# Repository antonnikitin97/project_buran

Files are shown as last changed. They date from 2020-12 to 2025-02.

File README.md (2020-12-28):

# project_buran
Files pertaining to my home-made Stream Deck project. 

## Motivation
I don't want to pay £150 for a stream deck

## Why Buran?
I decided some time ago to name all my personal projects after Russian space missions, буран (meaning, blizzard in Russian) was the Soviet Union's/Russia's attempt at a fully automated shuttle, it flew once successfully but was canned due to funding issues and the only existing model being destroyed.

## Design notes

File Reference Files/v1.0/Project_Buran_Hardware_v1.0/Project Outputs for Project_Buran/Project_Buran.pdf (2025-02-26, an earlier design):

Comment | Description | Designator | Footprint | LibRef | Quantity
GRM188R60J106ME47D | Chip Multilayer Ceramic Capacitors for General Purpose, 0603, 10uF, X5R, 15%, 20%, 6.3V | C1, C2, C11, C13, C14 | FP-GRM188-0_1-e0_2_0_55-IPC_A | CMP-2006-02792-2 | 5
ATSAMD11D14A-SSUT | Integrated Circuit | IC1 | SOIC127P1032X265-20N | ATSAMD11D14A-SSUT | 1
MAX803SQ308T1G | Integrated Circuit | IC2 | SOT65P220X100-3N | MAX803SQ308T1G | 1
LP5012RUKR | Integrated Circuit | IC5 | QFN40P300X300X80-21N-D | LP5012RUKR | 1
292303-7 | CONN RCPT USB2.0 TYPEA 4P SMD RA | J2 | FP-292303-7-MFG | CMP-03360-000008-1 | 1
61301021121 | THT Vertical Pin Header WR-PHD, Pitch 2.54 mm, Dual Row, 10 pins | P1 | 61301021121 | CMP-1502-01084-1 | 1
TLV75733PDBVR | Power Supply | PS1 | SOT95P280X145-5N | TLV75733PDBVR | 1
CRCW0603110RFKEA | | R1, R2, R3, R8 | RESC1609X50X30NL10 T20 | CMP-2000-03854-1 | 4
465M111172501 | WS-PBTL Illuminated THT Push Button Switch, Red & Green & Blue | S9, S11, S13, S15 | 465M111172501 | 465M111172501 | 4
FSM4JSMA | Swicth, SPST, 24 V, -35 to 85 degC, 4-Pin SMD, RoHS, Tape and Reel | SW2 | TECO-FSM4JSMA_V | CMP-2000-05602-2 | 1
AB15T-32.768KHZ | Crystal or Oscillator | Y1 | AB15T32768KHZ | AB15T-32.768KHZ | 1

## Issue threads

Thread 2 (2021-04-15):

Add thermal relief to pads that connect to GND plane

antonnikitin97, 2021-04-15:
This will make it easier to reflow solder on these pads

antonnikitin97, 2021-04-17:
resolved in 03a86d5f0a763ea9e13fac3a59dc2d1cc172d767

Closed 2021-04-17.

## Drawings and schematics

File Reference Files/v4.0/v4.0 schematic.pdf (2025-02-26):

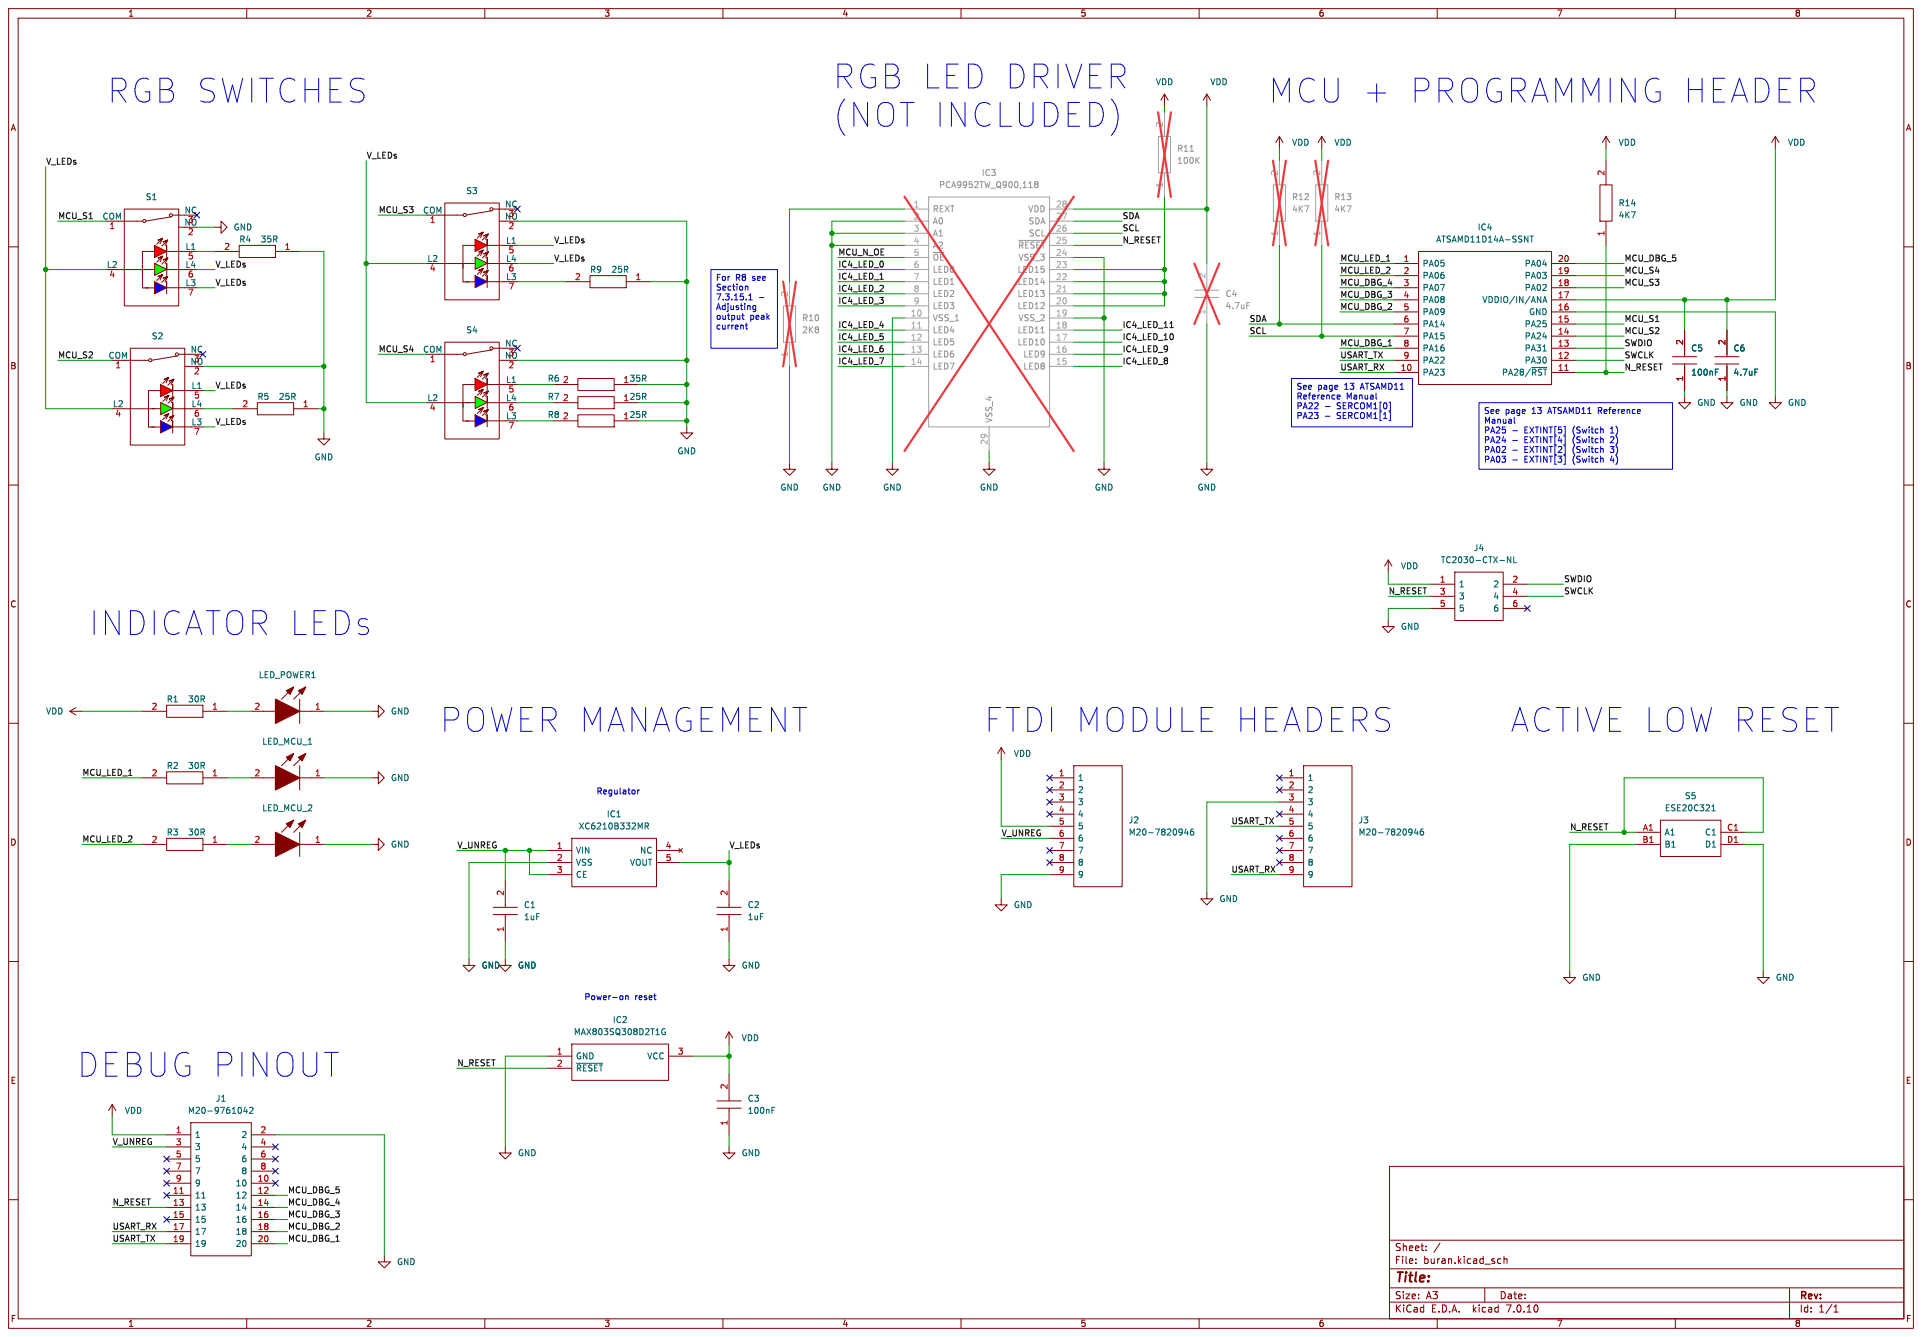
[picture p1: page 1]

See page 13 ATSAMD11 Reference Manual PA25 - EXTINT[5] (Switch 1) PA24 - EXTINT[4] (Switch 2) PA02 - EXTINT[2] (Switch 3) PA03 - EXTINT[3] (Switch 4) For R8 see Section

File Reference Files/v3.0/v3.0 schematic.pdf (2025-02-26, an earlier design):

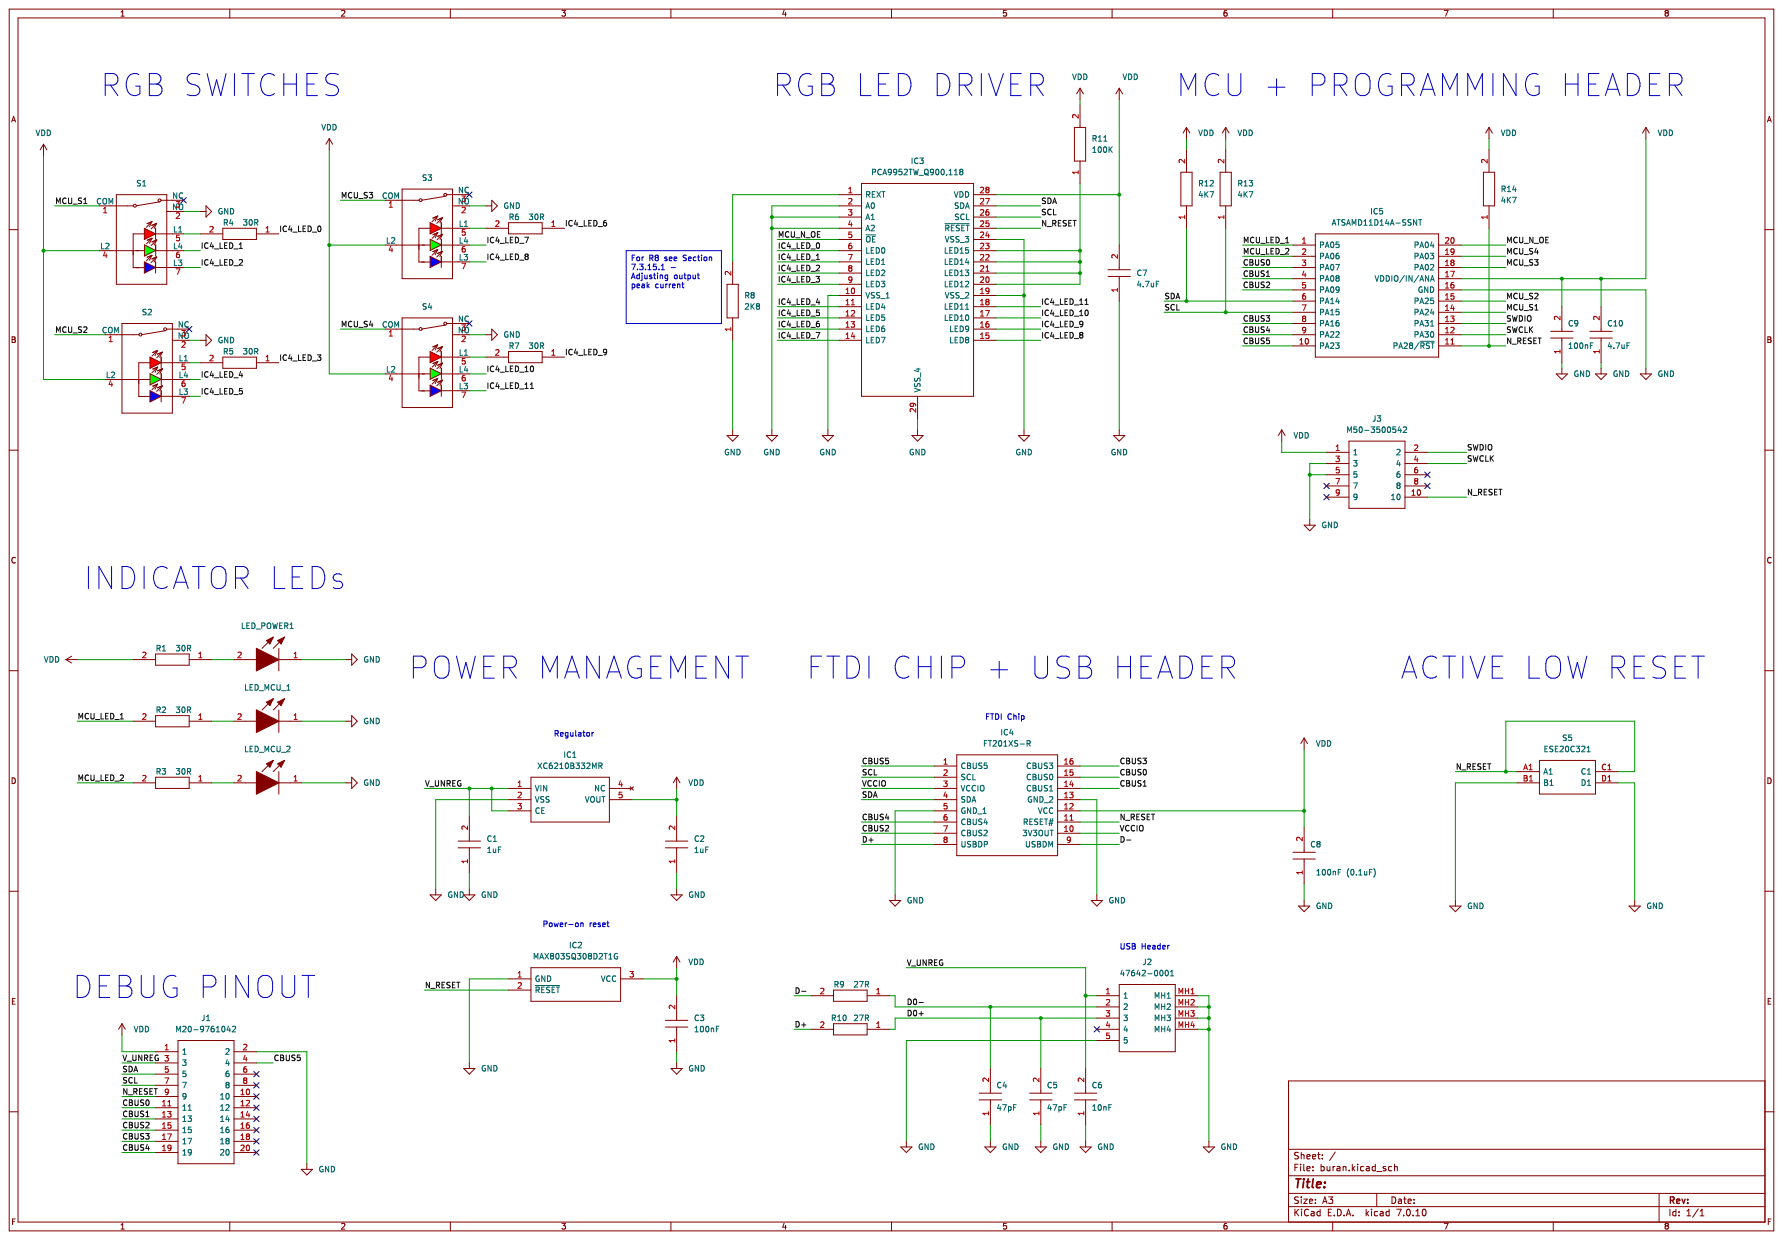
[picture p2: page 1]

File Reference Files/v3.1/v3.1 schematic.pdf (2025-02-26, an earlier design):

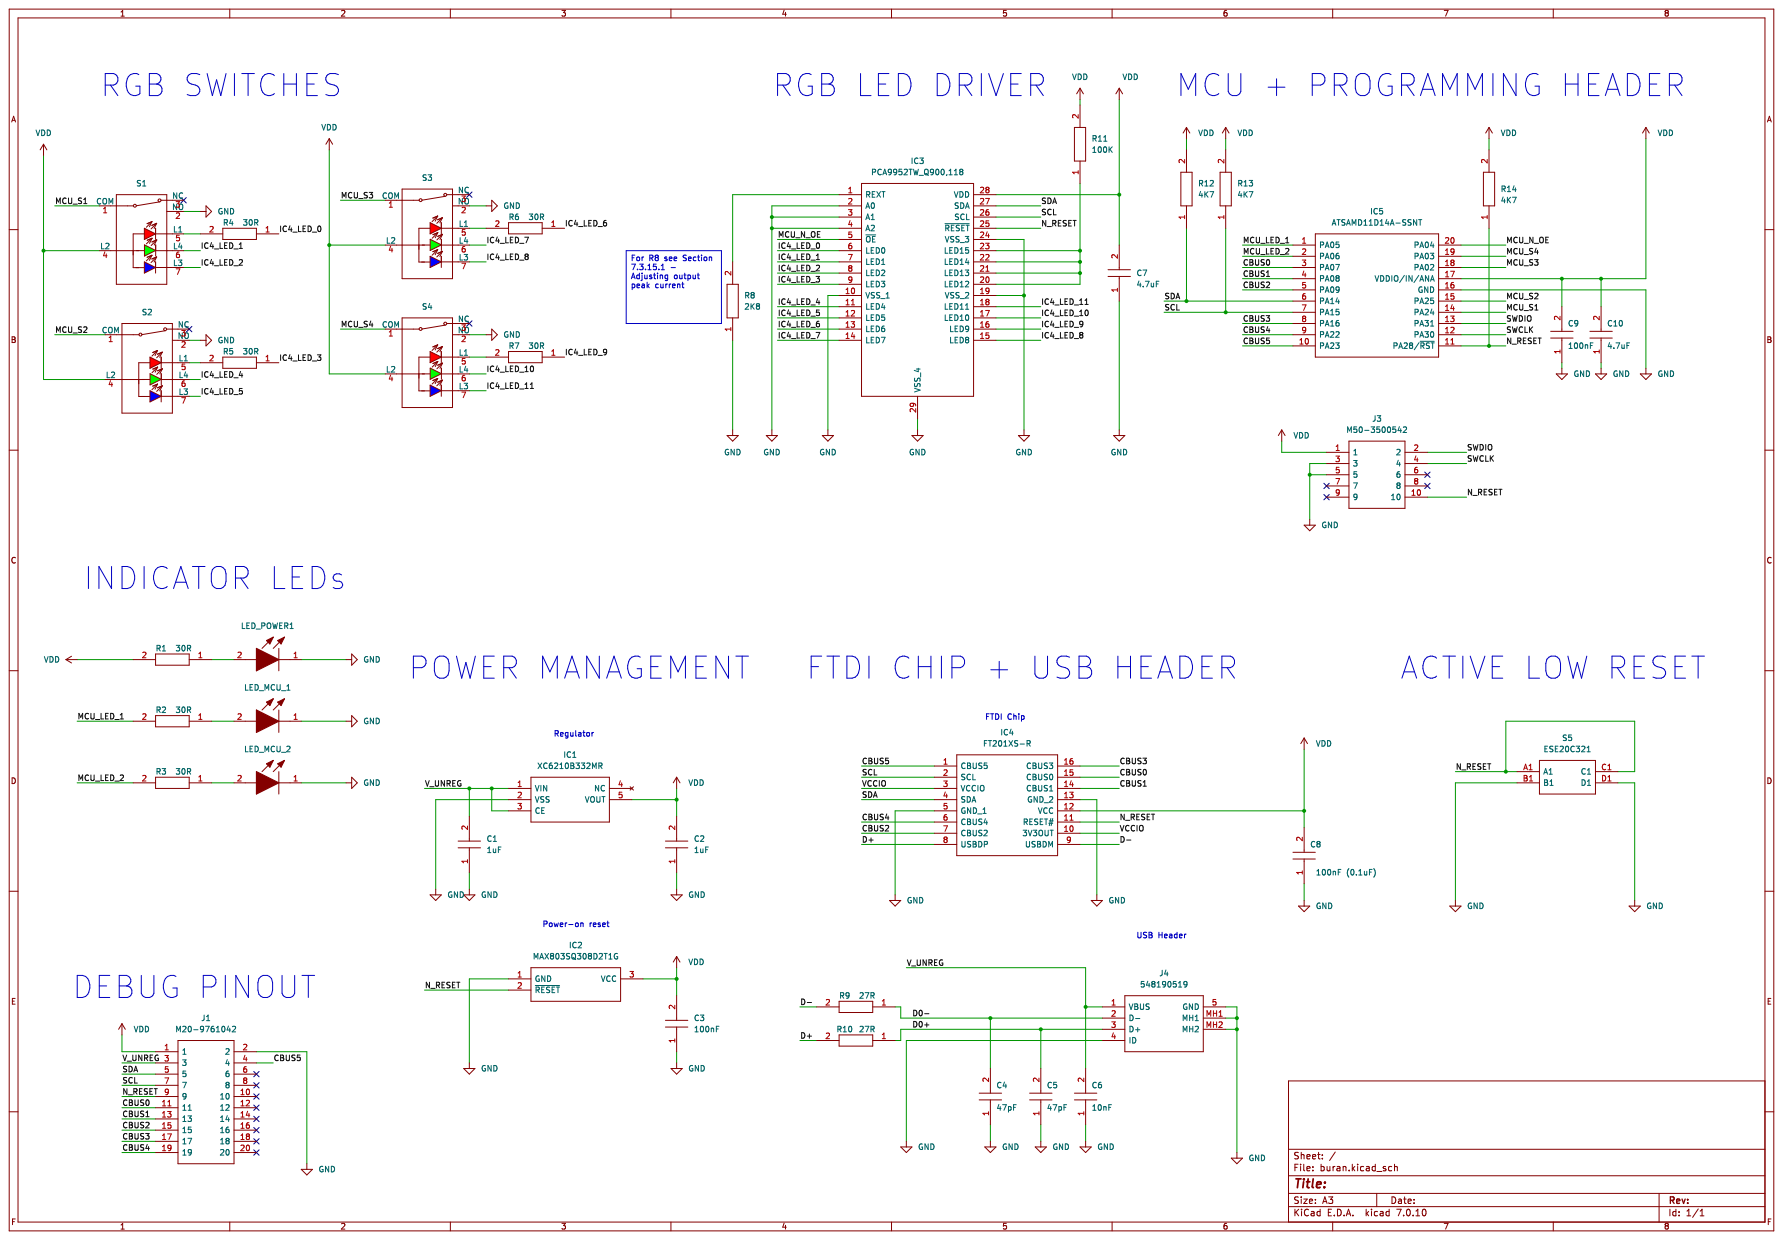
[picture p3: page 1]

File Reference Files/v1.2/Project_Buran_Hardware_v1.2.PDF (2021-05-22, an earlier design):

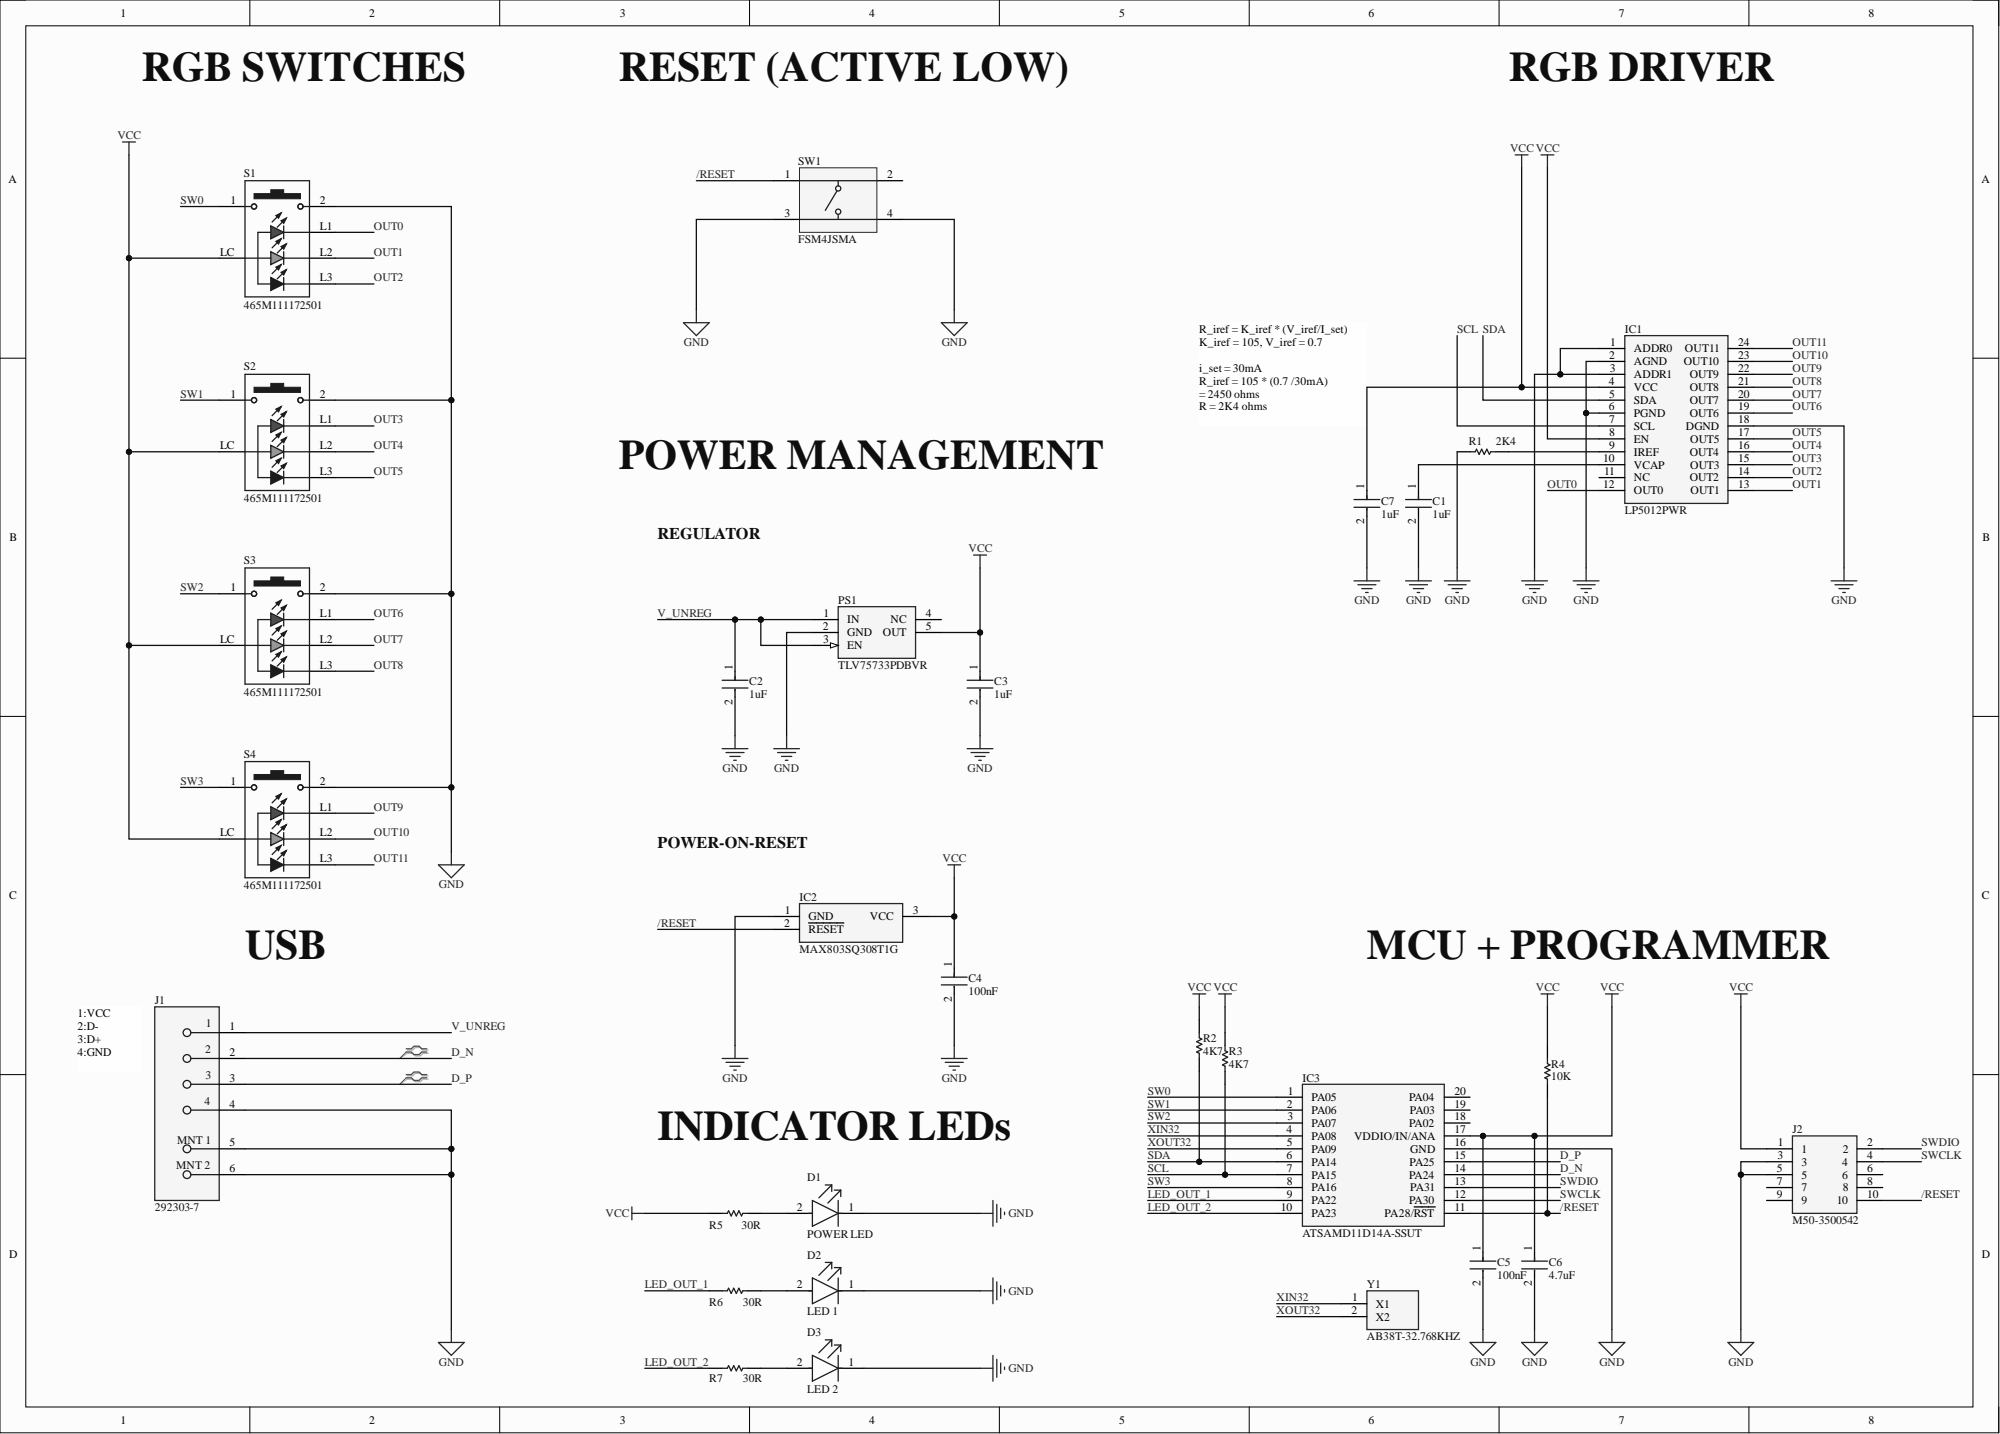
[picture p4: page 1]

AGND 2
ADDR1 3
VCC 4
SDA 5

SCL 7

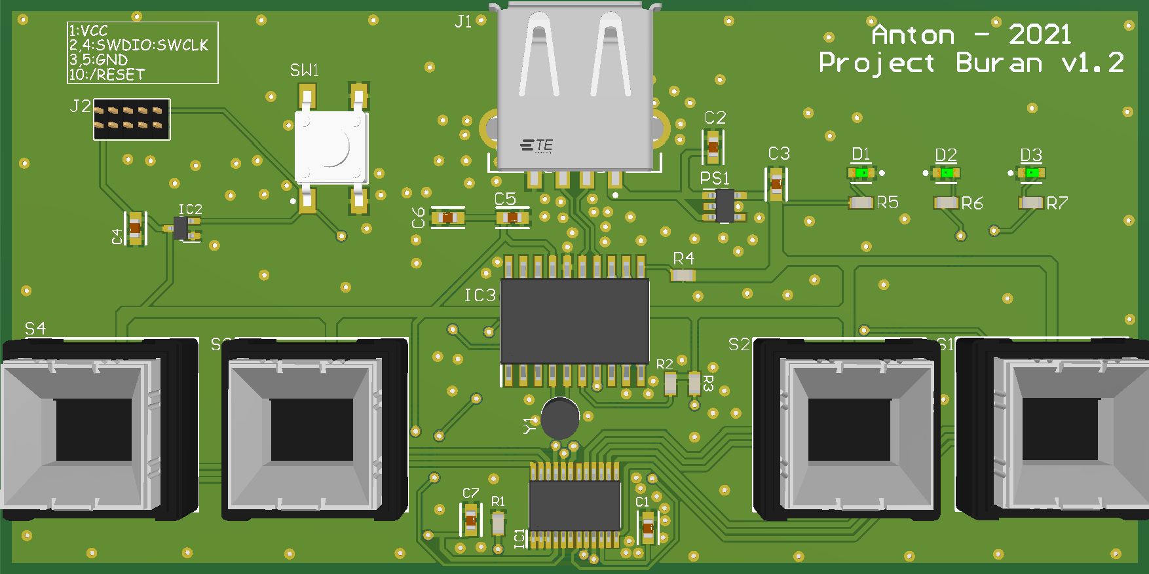
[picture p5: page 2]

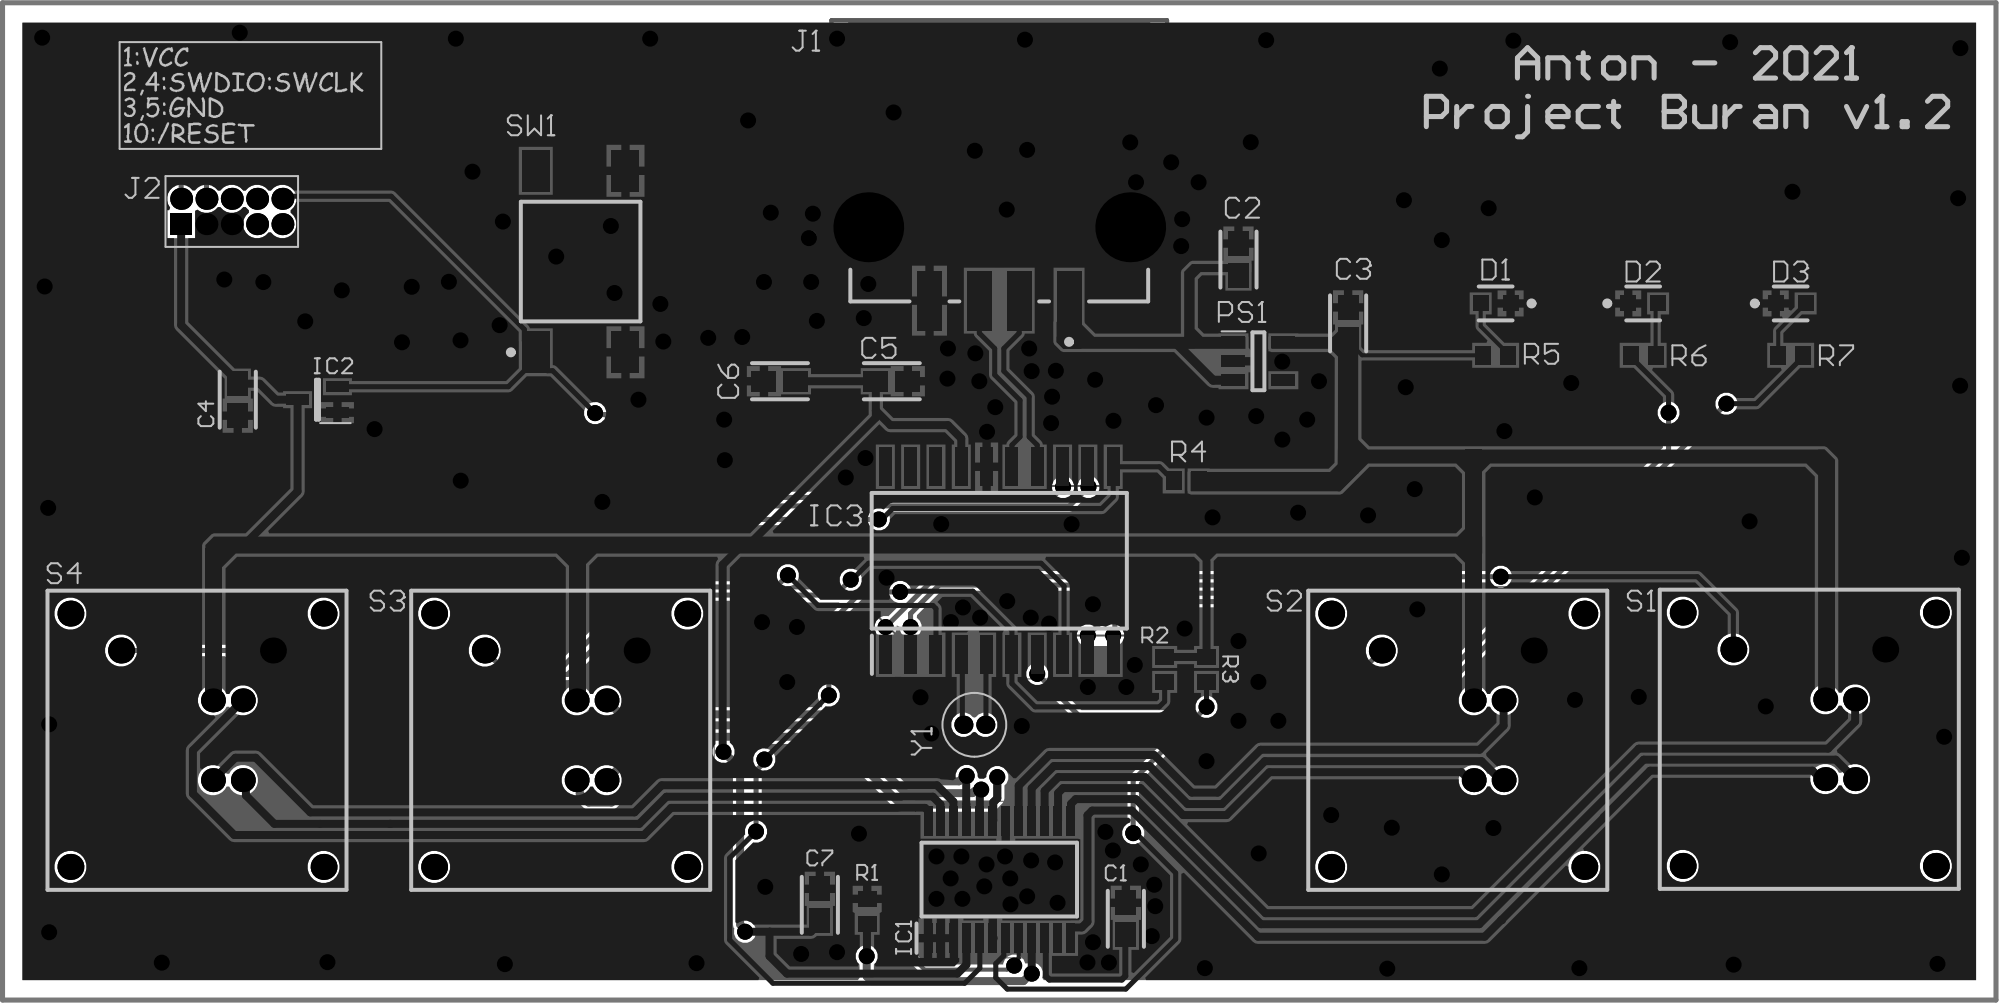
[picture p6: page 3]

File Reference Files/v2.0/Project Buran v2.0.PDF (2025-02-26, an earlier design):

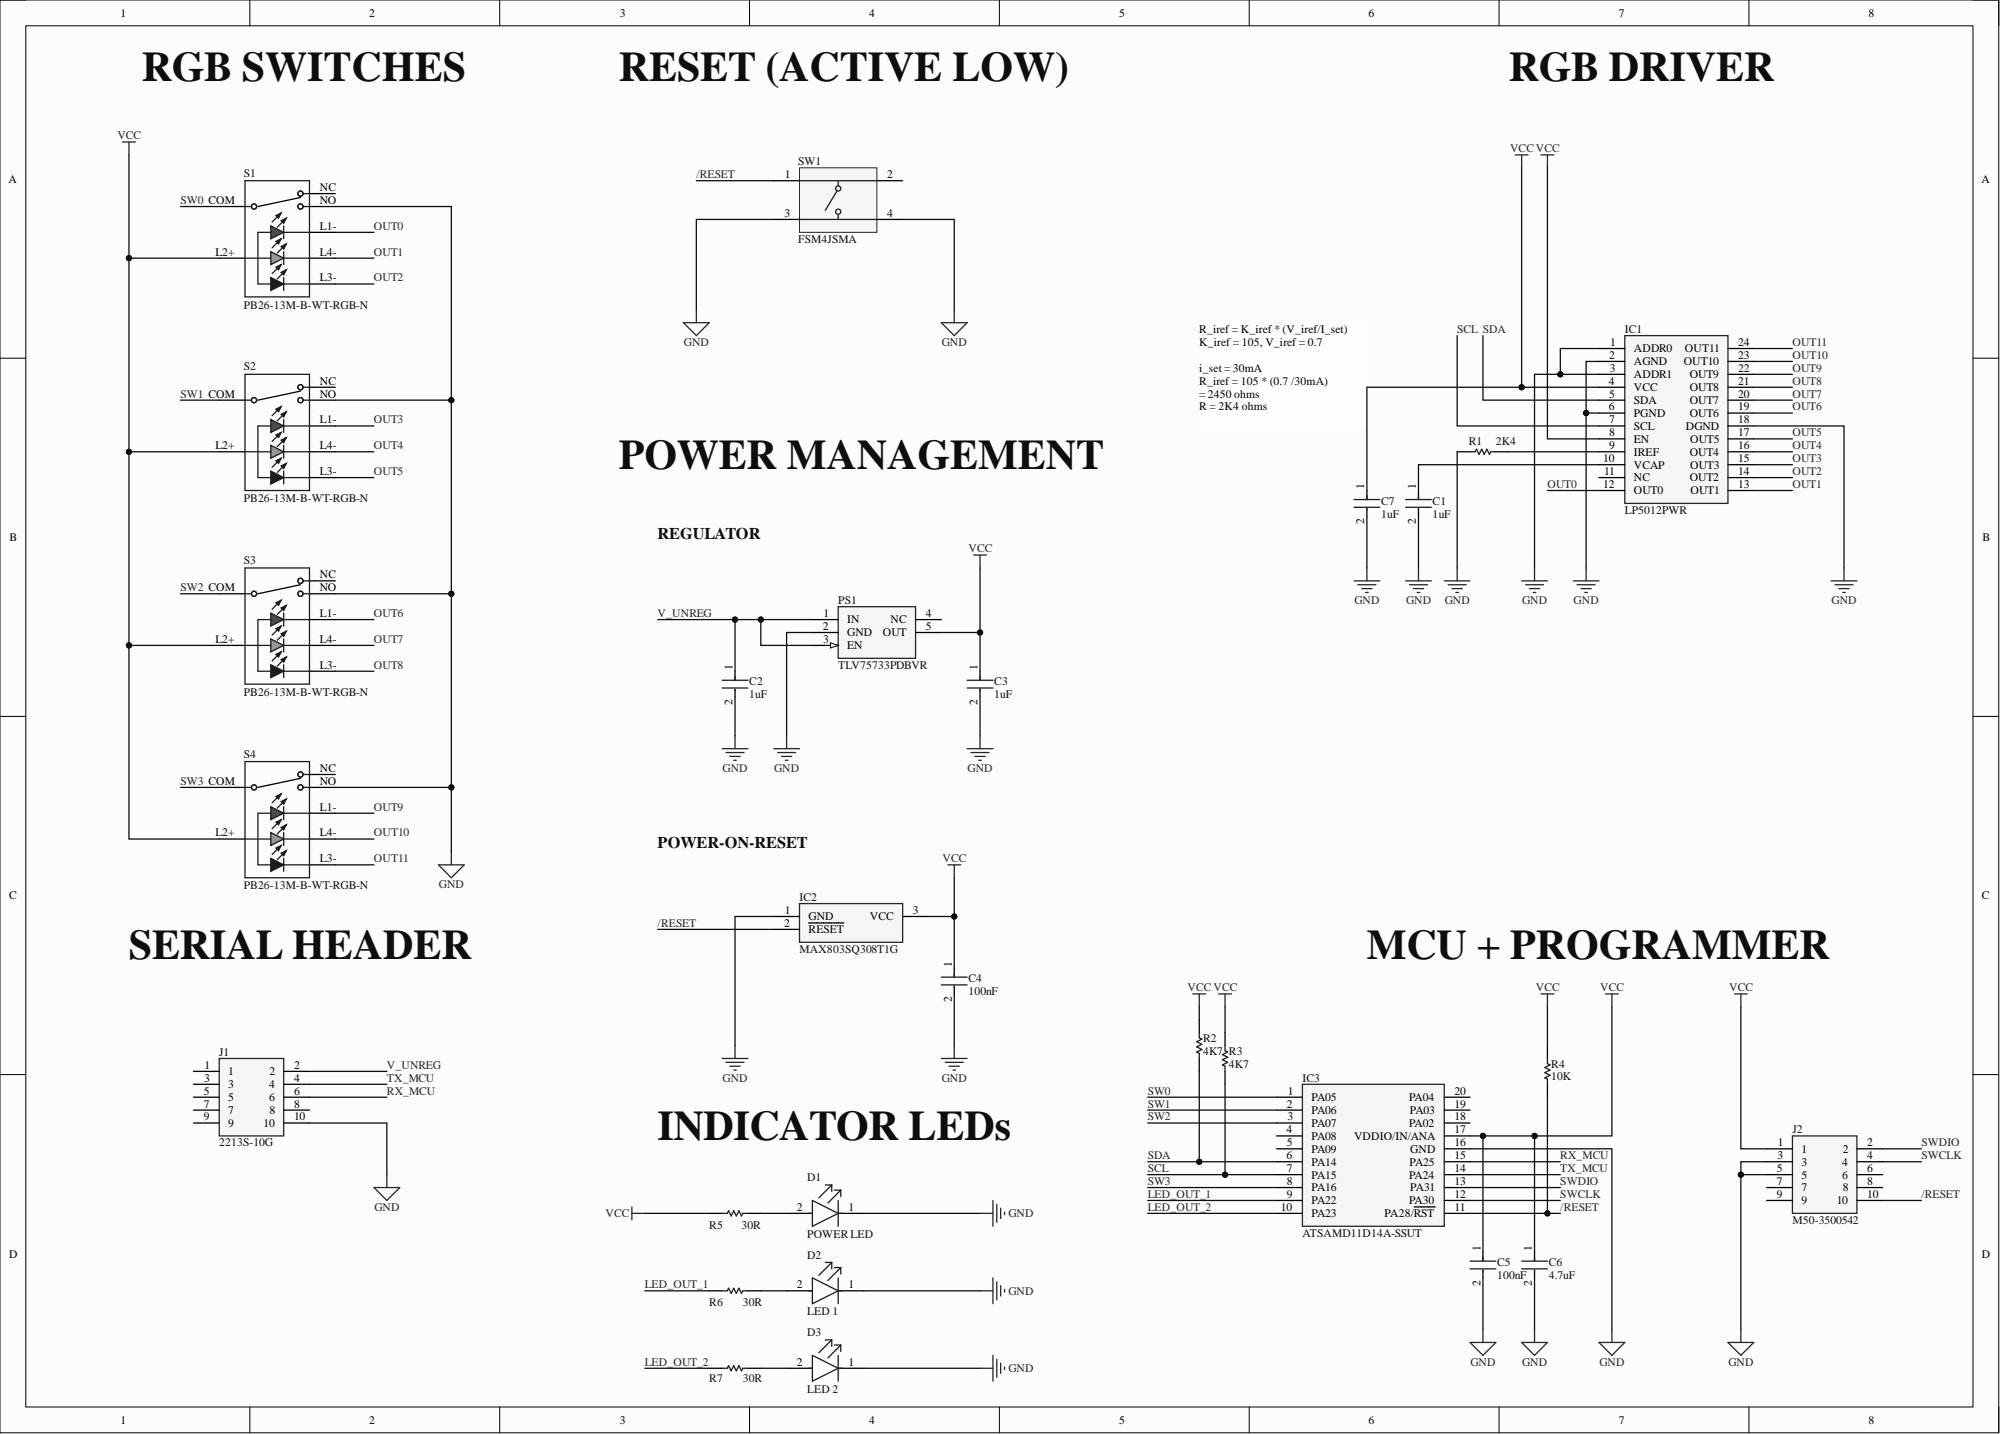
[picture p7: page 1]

AGND 2
ADDR1 3
VCC 4

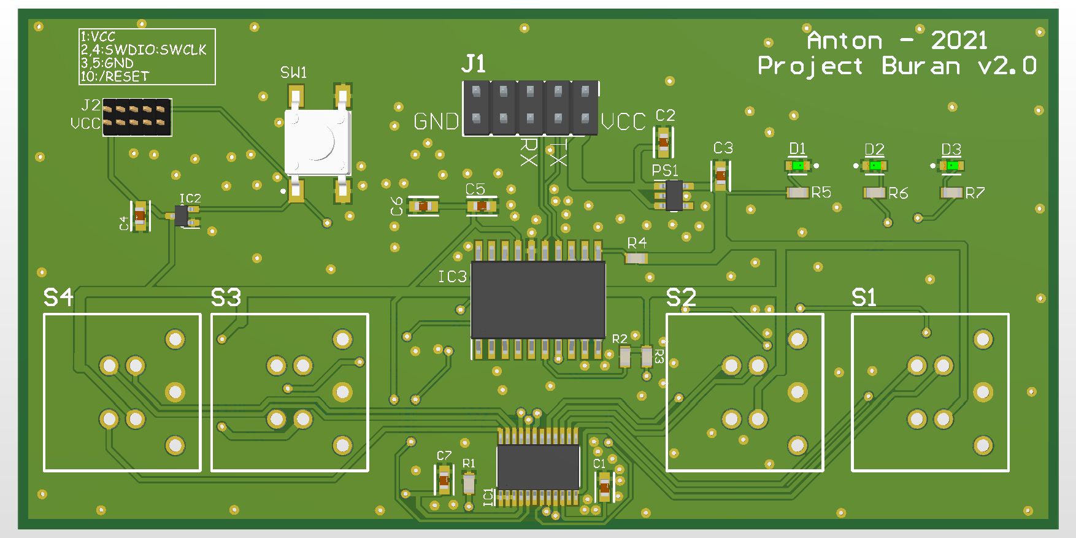
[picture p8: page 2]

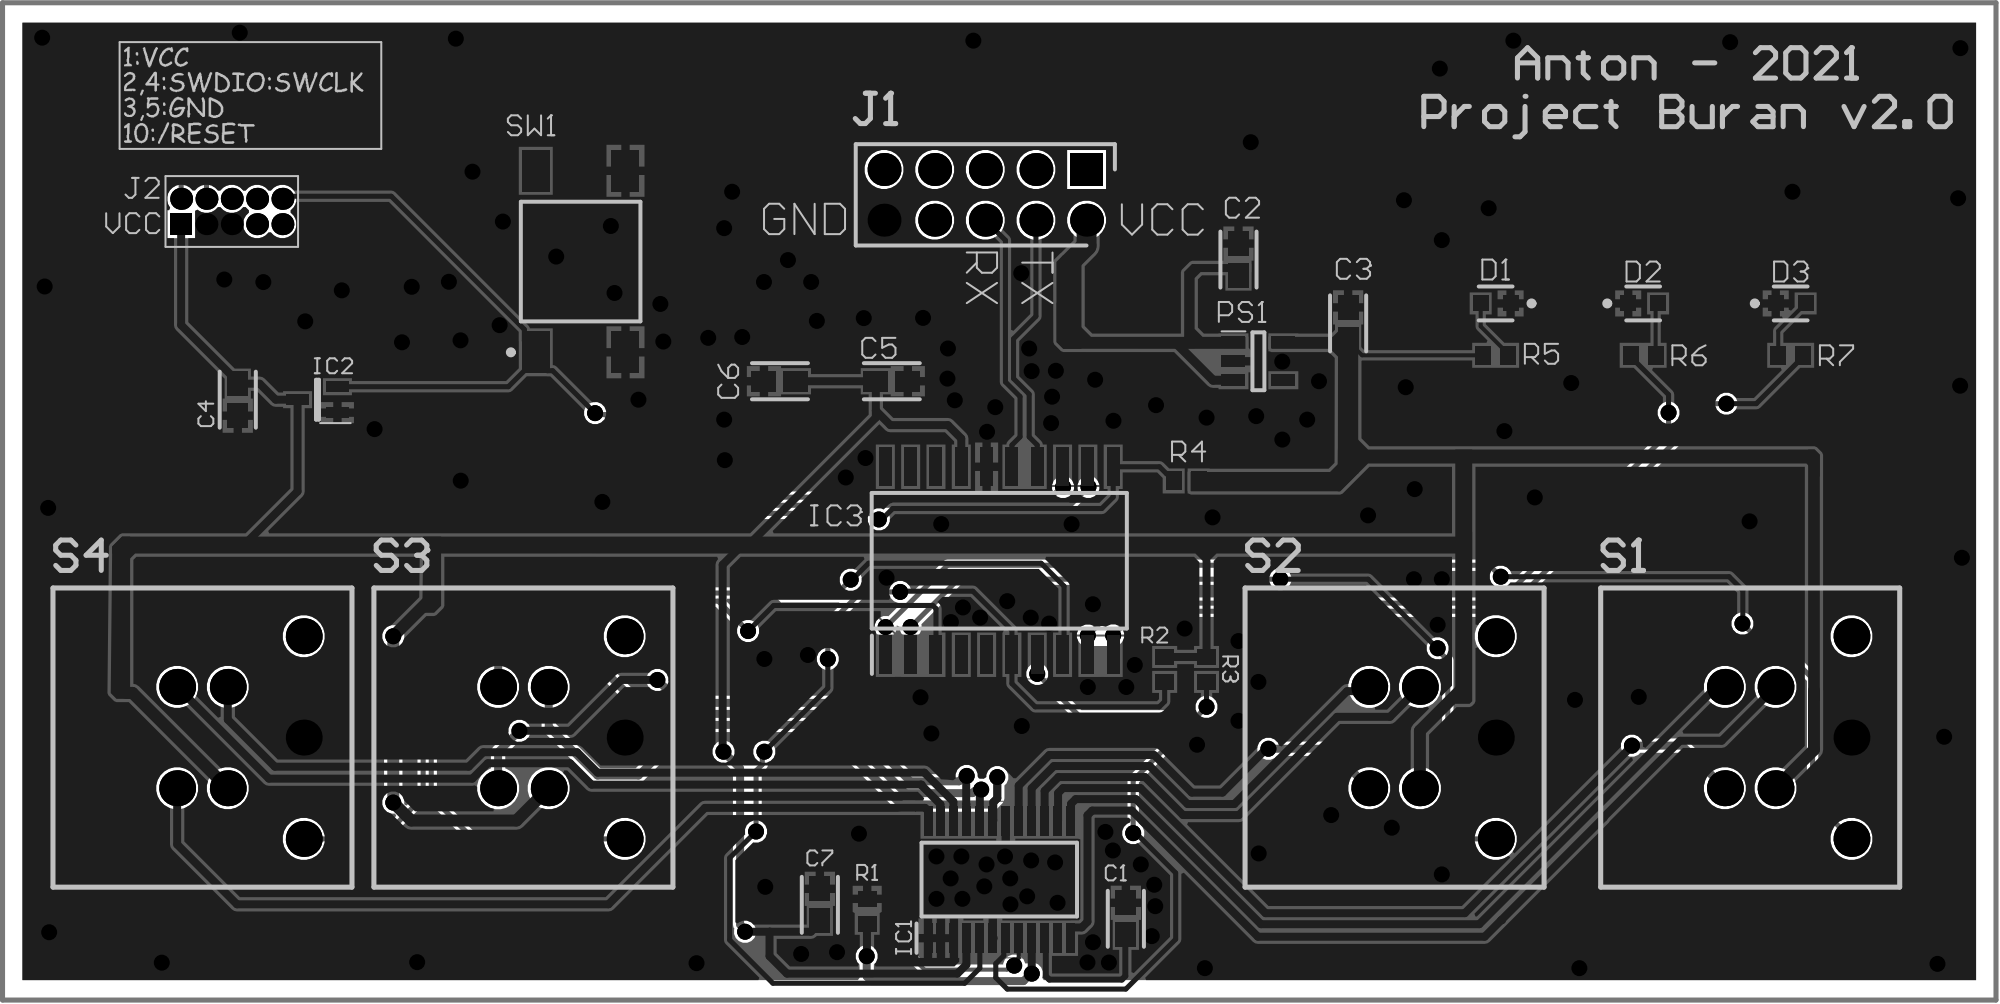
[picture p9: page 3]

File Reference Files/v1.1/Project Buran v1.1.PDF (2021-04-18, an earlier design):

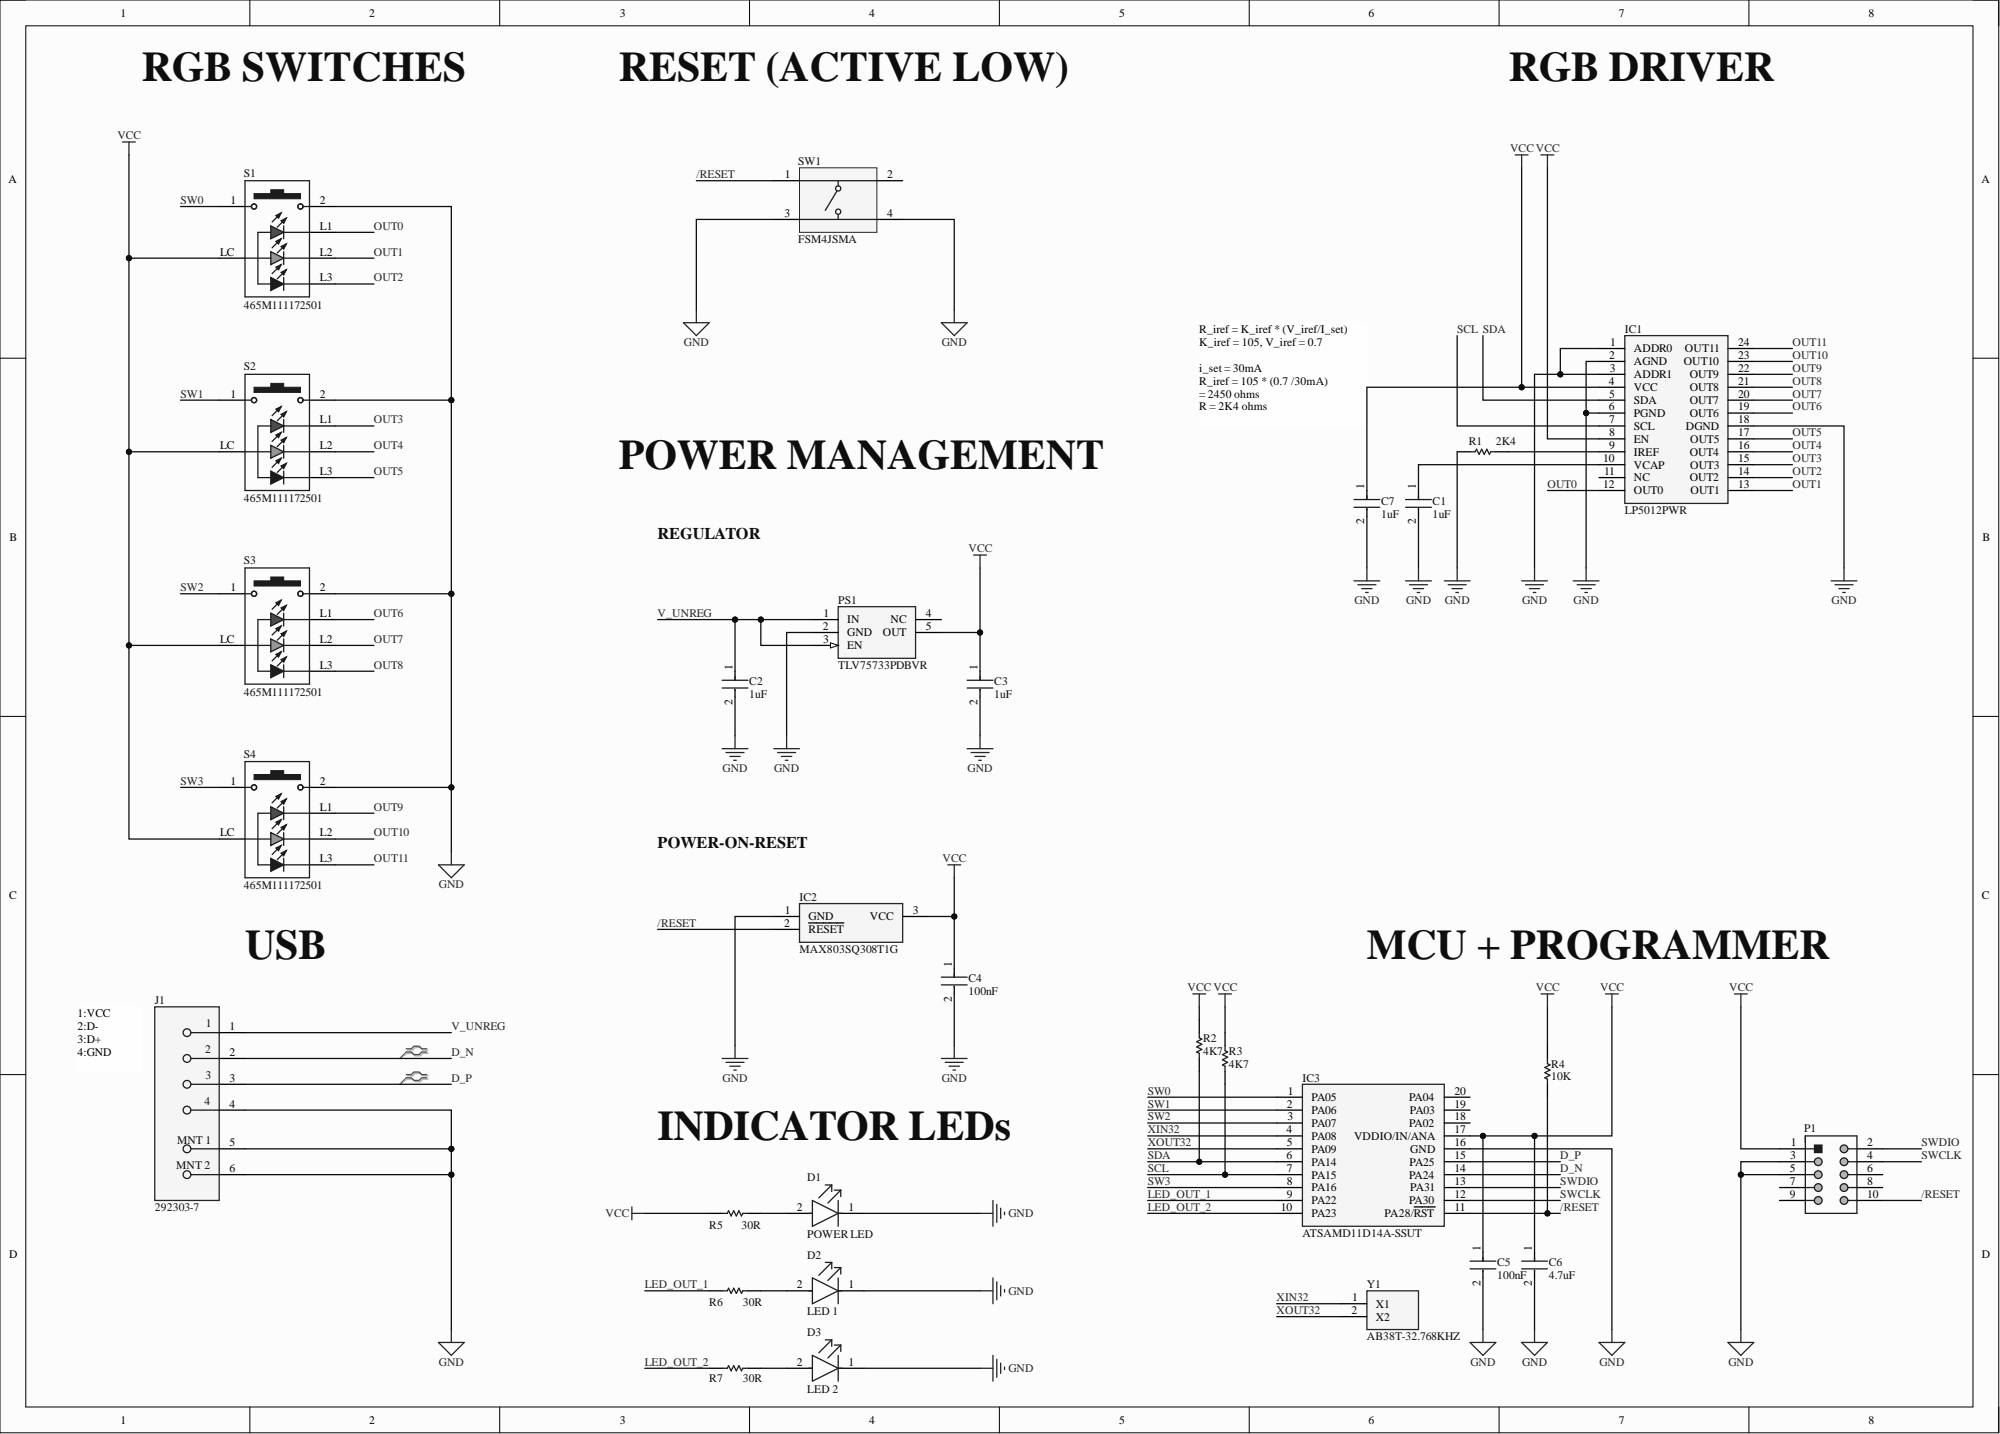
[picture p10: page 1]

AGND 2
ADDR1 3
VCC 4
SDA 5

SCL 7

IREF 9

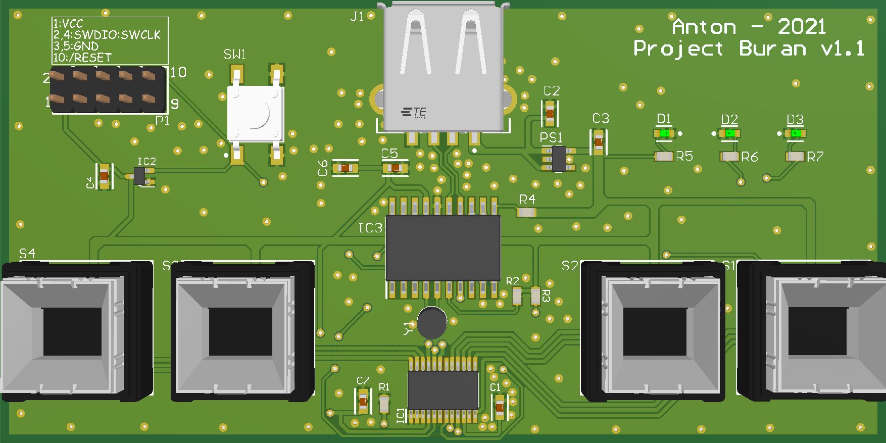
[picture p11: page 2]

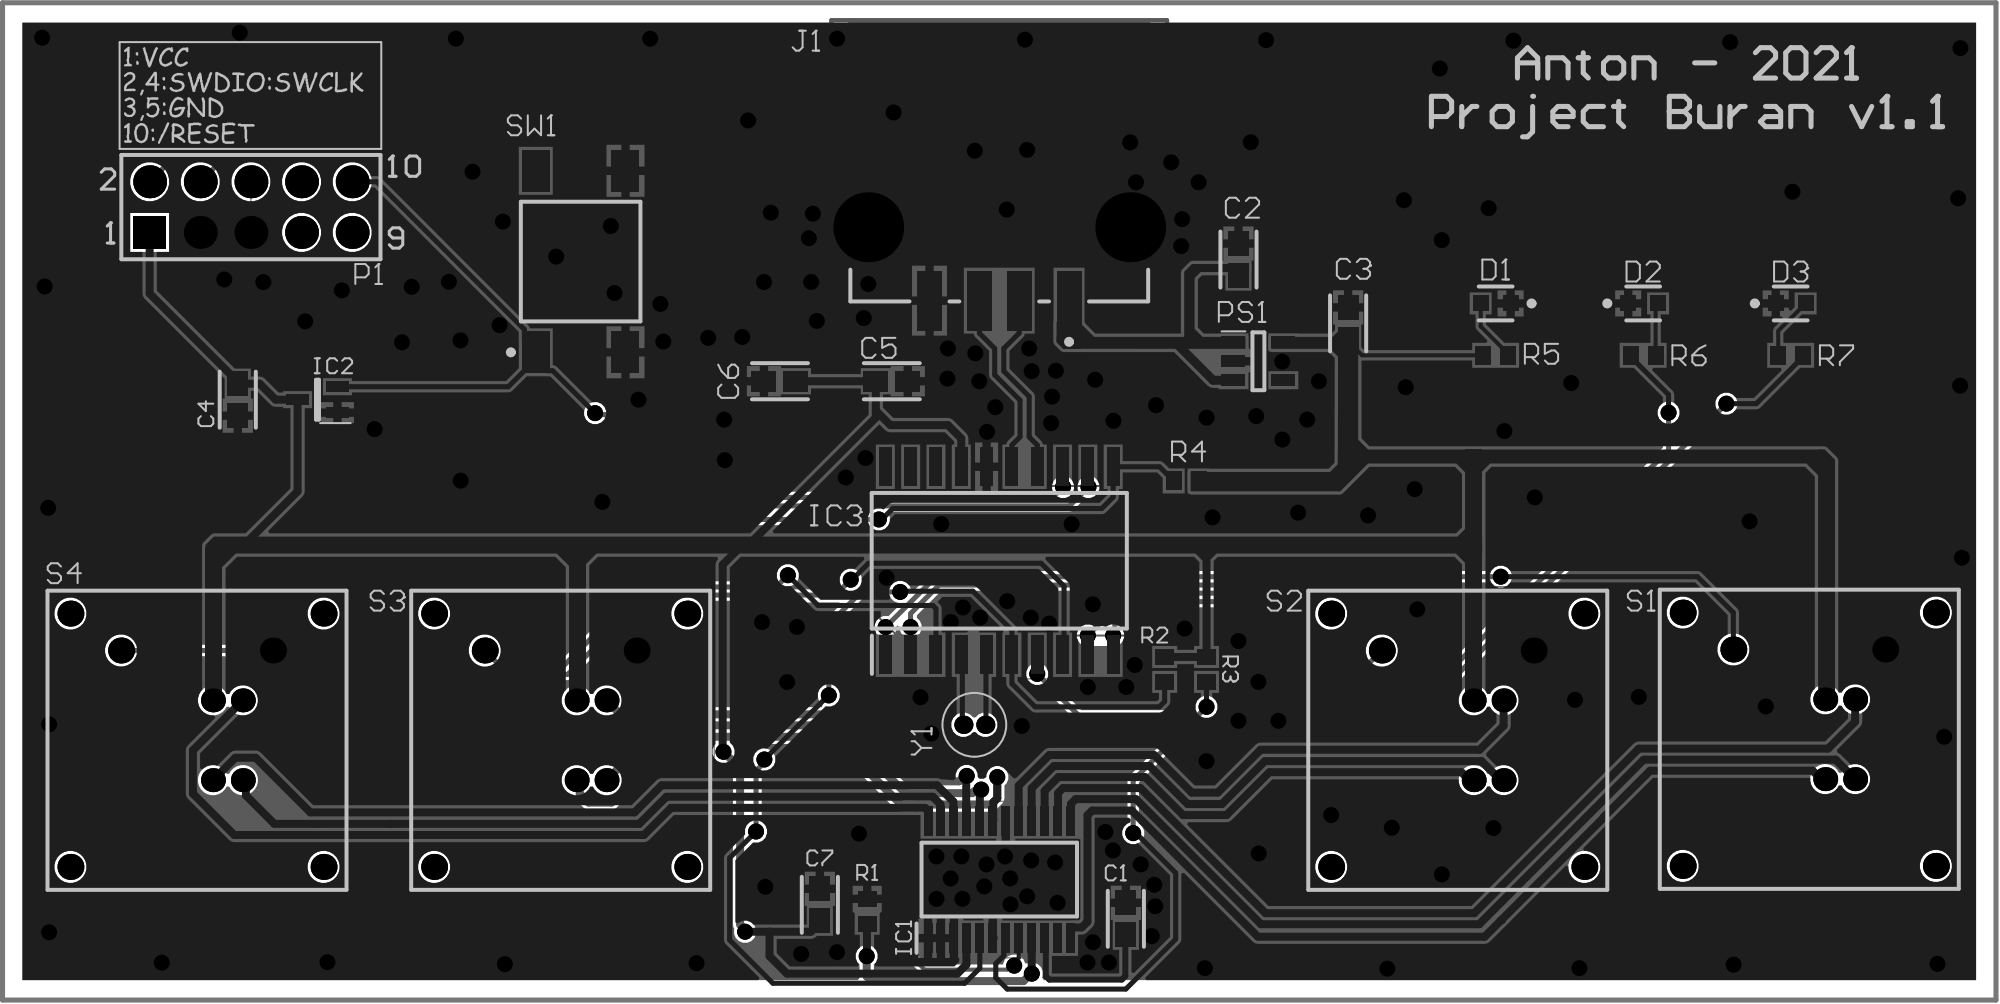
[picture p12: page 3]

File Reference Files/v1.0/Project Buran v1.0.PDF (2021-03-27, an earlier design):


AGND 2
ADDR1 3
VCC 4
SDA 5

SCL 7

IREF 9



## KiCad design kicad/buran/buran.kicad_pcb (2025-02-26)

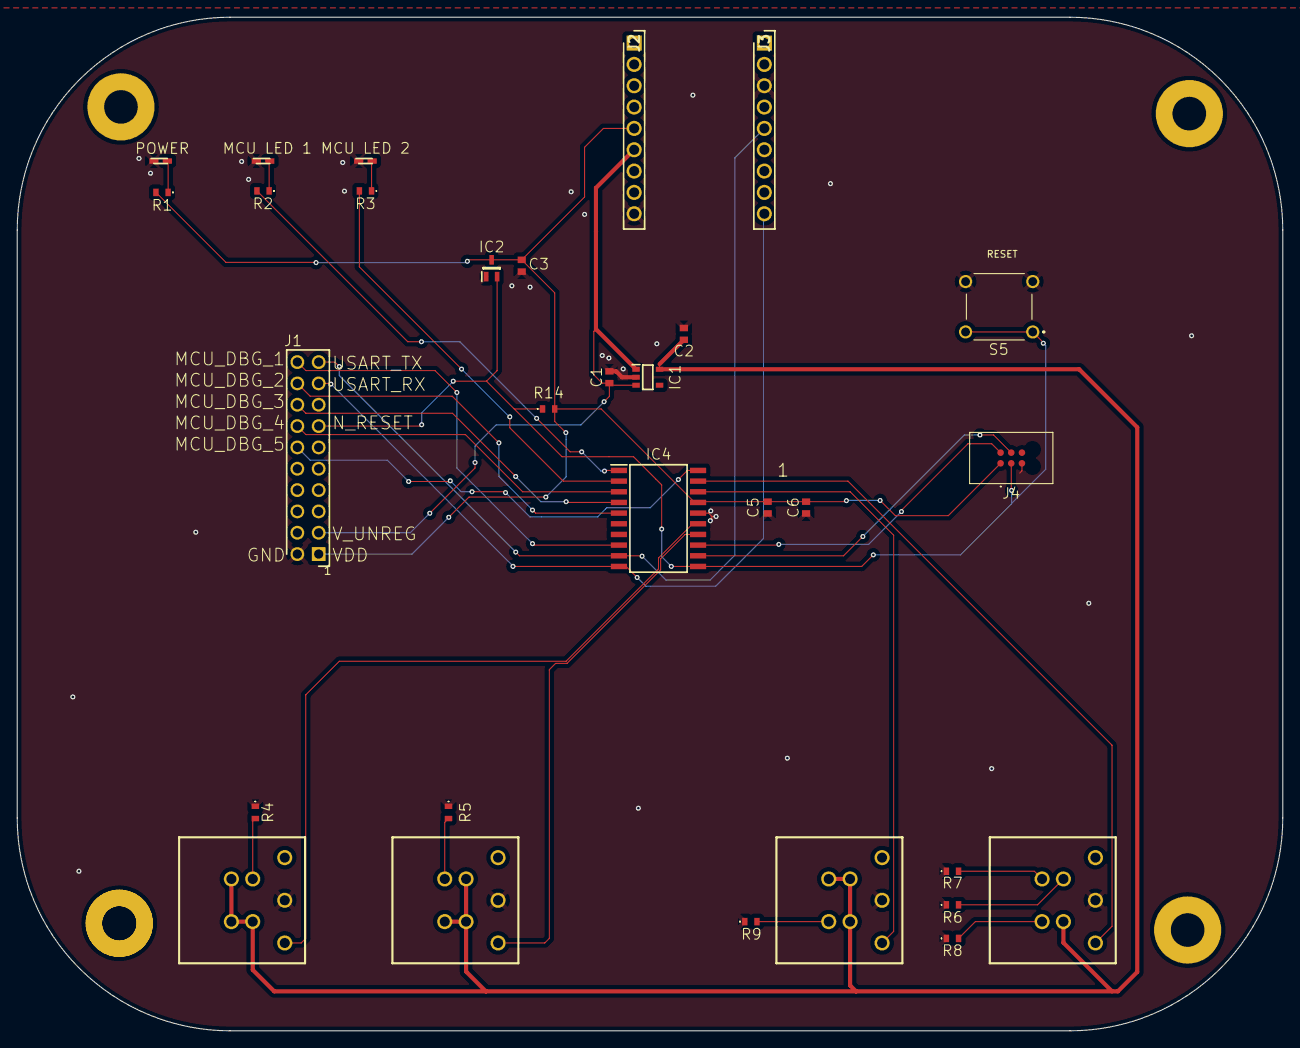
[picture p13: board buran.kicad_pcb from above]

Board: 2 copper layers, 150.7 x 120.7 mm, 30 parts (0 on the bottom side), 29 nets.

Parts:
C1, C2: 1uF; CAPC1608X87N
C3, C5: 100nF; CAPC1608X87N
C6: 4.7uF; CAPC1608X87N
IC1: XC6210B332MR; SOT95P280X130-5N
IC2: MAX803SQ308D2T1G; SOT65P220X100-3N
IC4: ATSAMD11D14A-SSNT; SOIC127P1032X265-20N
J1: M20-9761042; HDRV20W64P254_2X10_2540X508X838P
J2, J3: M20-7820946; RHDR9W70P0X254_1X9_2326X250X865P
J4: TC2030-CTX-NL; TC2030MCPNL10
MCU LED 1, MCU LED 2: HSMA-C120; LEDM166X110N
POWER : HSMA-C120; LEDM166X110N
R1, R2, R3, R4, R5, R6, R7, R8, R9: 30R; ERA3AEB101V
R14: 4K7; ERA3AEB101V
S1, S2, S3, S4: PB26-13M RGB LED
S5: ESE20C321

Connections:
/MCU_DBG_1: IC4.8 (PA16), J1.20
/MCU_DBG_2: IC4.5 (PA09), J1.18
/MCU_DBG_3: IC4.4 (PA08), J1.16
/MCU_DBG_4: IC4.3 (PA07), J1.14
/MCU_DBG_5: IC4.20 (PA04), J1.12
/MCU_LED_1: IC4.1 (PA05), R2.2
/MCU_LED_2: IC4.2 (PA06), R3.2
/MCU_S1: IC4.15 (PA25), S1.1 (COM)
/MCU_S2: IC4.14 (PA24), S2.1 (COM)
/MCU_S3: IC4.18 (PA02), S3.1 (COM)
/MCU_S4: IC4.19 (PA03), S4.1 (COM)
/N_RESET: IC2.2 (~RESET), IC4.11 (PA28/~RST), J1.13, J4.3, R14.1, S5.A1, S5.C1
/SWCLK: IC4.12 (PA30), J4.4
/SWDIO: IC4.13 (PA31), J4.2
/USART_RX: IC4.10 (PA23), J1.17, J3.9
/USART_TX: IC4.9 (PA22), J1.19, J3.5
/V_LEDs: C2.2, IC1.5 (VOUT), S1.4 (L2), S1.6 (L4), S1.7 (L3), S2.4 (L2), S2.5 (L1), S2.7 (L3), S3.4 (L2), S3.5 (L1), S3.6 (L4), S4.4 (L2)
/V_UNREG: C1.2, IC1.1 (VIN), IC1.3 (CE), J1.3, J2.6
GND: C1.1, C2.1, C3.1, C5.1, C6.1, IC1.2 (VSS), IC2.1 (GND), IC4.16 (GND), J1.2, J2.9, J3.3, J4.5, MCU LED 1.1, MCU LED 2.1, POWER.1, R4.1, R5.1, R6.1, R7.1, R8.1, R9.1, S1.2 (NO), S2.2 (NO), S3.2 (NO), S4.2 (NO), S5.B1, S5.D1
unnamed: MCU LED 1.2, R2.1
unnamed: MCU LED 2.2, R3.1
unnamed: POWER.2, R1.1
unnamed: R4.2, S1.5 (L1)
unnamed: R5.2, S2.6 (L4)
unnamed: R9.2, S3.7 (L3)
unnamed: R6.2, S4.5 (L1)
unnamed: R8.2, S4.7 (L3)
unnamed: R7.2, S4.6 (L4)
VDD: C3.2, C5.2, C6.2, IC2.3 (VCC), IC4.17 (VDDIO/IN/ANA), J1.1, J2.5, J4.1, R1.2, R14.2

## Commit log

2020-12-24 initial project upload
    [Project_Buran.PrjPcb, project_buran.PcbDoc, project_buran.SchDoc]
2020-12-26 modify PCB shape to 150x80mm
    [project_buran.PcbDoc]
2020-12-27 add switches, usb components, LEDs, MCU
    [project_buran.SchDoc]
2020-12-28 add labels for connections
    [project_buran.SchDoc]
2020-12-28 add power regulation block and decoupling caps
    [project_buran.SchDoc]
2020-12-28 add further labels to ports on components
    [project_buran.SchDoc]
2020-12-28 add usb series resistors
    [project_buran.SchDoc]
2020-12-28 add components to layout
    [project_buran.PcbDoc]
2020-12-29 update page size to a2 to give more space
    [project_buran.SchDoc]
2020-12-29 add labels to mcu, switch connections
    [project_buran.SchDoc]
2020-12-29 add updi header to schematic
    [project_buran.SchDoc]
2020-12-29 add crystal oscilator for usb
    [project_buran.SchDoc]
2020-12-30 update schematic with usb ic net labels
    [project_buran.SchDoc]
2021-01-17 update project
    [Project_Buran.PrjPcb]
2021-01-27 update schematic for component models
    [project_buran.SchDoc]
2021-02-10 update pcb and schematic
    [project_buran.PcbDoc, project_buran_pcb.PcbDoc, project_buran_schematic.SchDoc]
2021-02-10 update components on pcb, initial layout
    [project_buran_pcb.PcbDoc]
2021-02-12 update pcb layout for 4 switches
    [project_buran_pcb.PcbDoc]
2021-03-14 revamp schematic, remove usb controller, change microcontroller
    [project_buran_schematic.SchDoc]
2021-03-14 change PCB shape, add new components
    [project_buran_a01.PcbDoc, project_buran_pcb.PcbDoc]
2021-03-15 add power-on-reset circuitry
    [project_buran_schematic.SchDoc]
2021-03-16 preliminary placement of components on pcb
    [project_buran_a01.PcbDoc]
2021-03-16 add decoupling cap to mcu vcc line
    [project_buran_schematic.SchDoc]
2021-03-16 whole project commit
    [Project_Buran.PrjPcb]
2021-03-17 update power lines for regulator
    [project_buran_a01.PcbDoc]
2021-03-17 add new RGB driver part (different footprint)
    [project_buran_schematic.SchDoc]
2021-03-19 add indicator LED to schematic, change crystal for DRC
    [project_buran_schematic.SchDoc]
2021-03-19 add more indicator leds to schematic
    [project_buran_schematic.SchDoc]
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2021-03-20 change folder structure for pcb files
    [Project_Buran.PrjPcb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]
2021-03-20 Delete Project_Buran directory
    remove old project directory
    [Project_Buran.PrjPcb, project_buran_a01.PcbDoc, project_buran_schematic.SchDoc]
2021-03-21 preliminary layout
    [project_buran_a01.PcbDoc]
2021-03-21 add decoupling cap for rgb driver vcc
    [project_buran_schematic.SchDoc]
2021-03-21 add in decoup cap after issue with schem
    [project_buran_a01.PcbDoc]
2021-03-21 finish prelim layout, add gnd vias and stitching
    [project_buran_a01.PcbDoc]
2021-03-21 add more vias for grounding
    [project_buran_a01.PcbDoc]
2021-03-22 add some more vias for good grounding
    [project_buran_a01.PcbDoc]
2021-03-23 move sda line away from 32khz crystal, change length of usb pairs
    [project_buran_a01.PcbDoc]
2021-03-27 update schematic component values for resistors and capacitors
    [project_buran_schematic.SchDoc]
2021-04-15 update revision to a02
    [Project_Buran.PrjPcb, project_buran_a02.PcbDoc, project_buran_schematic_a02.SchDoc]
2021-04-15 readd a01 and rename to general project_buran
    [Project_Buran.PrjPcb, project_buran.PcbDoc, project_buran_schematic.SchDoc]
2021-04-15 add new connector to pcb layout
    [project_buran.PcbDoc]
2021-04-15 add new usb connector to schematic
    [project_buran_schematic.SchDoc]
2021-04-15 update revision number
    [project_buran.PcbDoc]
2021-04-17 add thermal relief to pads to smd pads that connect to GND plane
    [project_buran_a01.PcbDoc]
2021-04-17 update meme format, move some layout for better GND connection
    [project_buran_a01.PcbDoc]
2021-04-17 add label to programming header for convenience
    [project_buran_a01.PcbDoc]
2021-04-17 change led labels to correct names
    [project_buran_schematic.SchDoc]
2021-04-17 final v1.1 layout
    [project_buran_a01.PcbDoc]
2021-04-18 move vias away from doge
    [project_buran_a01.PcbDoc]
2021-04-18 fix altium project after removal of other files
    [Project_Buran.PrjPcb, project_buran_a01.PcbDoc]
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2021-05-16 update schematic for v2. Add more buttons, change some MCU connections
    [Project_Buran.PrjPcb, project_buran_schematic.SchDoc]
2021-05-17 begin layout for v2
    [project_buran.PcbDoc, project_buran_a01.PcbDoc]
2021-05-21 work on v2 layout
    [Project_Buran.PrjPcb, project_buran.PcbDoc, project_buran_schematic.SchDoc]
2021-05-22 remove uneeded schematic files
    [project_buran_a02.PcbDoc, project_buran_schematic_a02.SchDoc]
2021-07-10 add io exapander and test points for v2
    [project_buran_schematic.SchDoc]
2021-12-04 replace usb header with pins
    [project_buran_a01.PcbDoc]
2021-12-04 replace usb with serial header
    [project_buran_schematic.SchDoc]
2021-12-04 replace usb header with serial header
    [Project_Buran.PrjPcb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]
2022-07-19 Update files
    [Project_Buran.PrjPcb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]
2022-09-25 add i2c usb chip
    [Project_Buran.PrjPcb, project_buran_a01.PcbDoc, project_buran_schematic.SchDoc]
2022-11-13 Update schematic, begin new layout
    [Project_Buran.PrjPcb, project_buran.PcbDoc, project_buran_a01.PcbDoc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]
2024-01-21 Add kicad files
    [BuranComponent.PcbLib, BuranComponent.SchLib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]
2024-05-22 kicad files
    [Project_Buran.PrjPcb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]
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2025-02-26 reference files for v3.0
    [Project_Buran.PrjPcb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]
